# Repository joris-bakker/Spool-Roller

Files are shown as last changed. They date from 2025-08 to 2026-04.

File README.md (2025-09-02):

# Spool-Roller (Made by Josua T. and Joris Bakker)

WhatsApp Image

- ToDO: Nach Manual-Menu Stop, wenn man wieder zurückgeht, den Screen aktualisieren!
- Gehäuse für Platine
- 3D-Files hochladen 

All designs, CAD-Files and mechanical parts and were created by Josua T.

Software and PCB was made by Joris Bakker

# Device Function Description

The device is designed for winding various materials, such as wire, filament, or cable.  
The basic principle is based on two main components:

- **Guide Unit**: Moves smoothly back and forth to ensure the material is wound neatly and in parallel.  
- **Drive Roller**: Winds the material onto the spool.

This technology allows spools to be filled automatically and evenly.

---

## Operating Modes

### 1. Automatic Mode

The user specifies the following parameters:

- Number of windings  
- Wire diameter  
- Spool width  

The winding process is fully automated according to the set values.  
This mode is particularly suitable for manufacturing custom spools, such as induction coils.

---

### 2. Manual Mode

- No input of winding data required.  
- The winding speed is manually controlled via a rotary knob.

---

## Operating Instructions

### 1. Preparation

1. Power on the device.  
2. Select one of the two operating modes (Automatic or Manual) via the menu.  
3. If necessary, set the parameters (e.g., winding count, wire diameter, spool width).  

**Note:** During parameter entry, all motors are disabled and mechanically free to move.

---

### 2. Guide Zeroing

1. After entering the parameters, move the guide to the left edge of the guide rail.  
2. This position is set as the zero point.

---

### 3. Spool Preparation

1. Mount an empty spool on the device.  
   - The clamping mechanism works similarly to a lathe chuck.  
2. Thread the material (e.g., wire, filament, or cable) through the guide.  
3. Secure the material end firmly to the spool.  
4. Apply light tension to the material to ensure neat winding.

---

### 4. Starting the Winding Process

After zeroing, the selected operating mode starts automatically:

- **Automatic Mode:** Winding is performed according to the set parameters.  
- **Manual Mode:** Winding speed is controlled via the rotary knob.

---

## Software and Control Layout

### Control Concept

**Control Element:**  
All menu items are controlled via a rotary knob with a push function.

- **Rotate:** Navigate between menu items  
- **Push:** Select a menu item or confirm an entry  

**Display:**  
An OLED display shows all available functions, menus, and status messages of the device.

---

## Device Control

- **Main Switch:** Located on the device housing for turning the entire unit on/off.  
- **Power Supply:**  
  - Power adapter: 12 V, minimum 3 A output  
  - Power consumption: approx. 1.8 A during operation  

---

## Electronics Layout

- **Central Control Unit:**  
  - ESP32 microcontroller for motor control, display management, and user interaction  

- **Motor Drivers:**  
  - Two separate drivers for controlling the different motors  

- **Power Conversion:**  
  - DC-to-DC voltage converters for internal circuits and voltage adjustment  

---

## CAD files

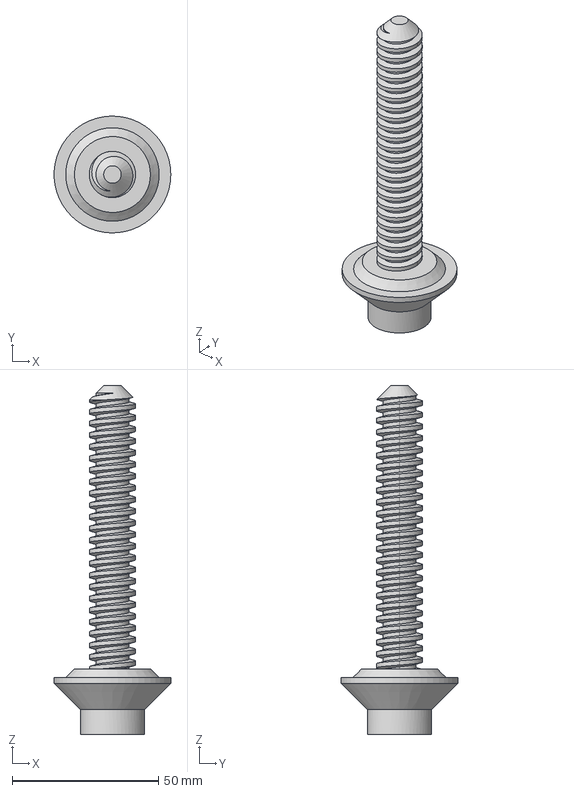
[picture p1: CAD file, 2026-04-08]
3D-Models/Spulenschraube.step
40.0 x 40.0 x 119.5 mm

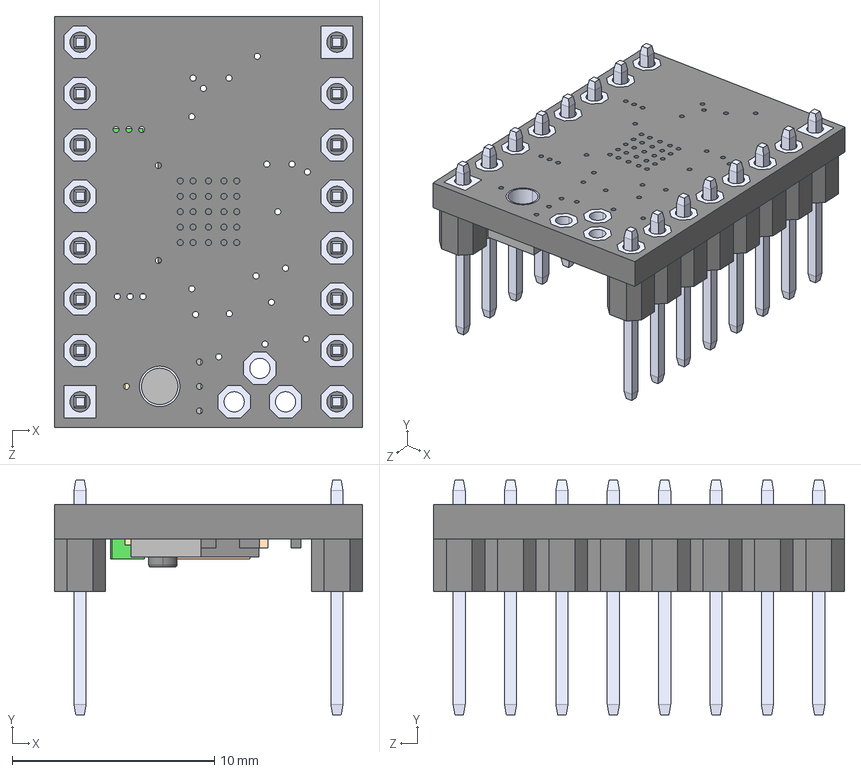
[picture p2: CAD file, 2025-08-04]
kiCad-FIles/additional_files/TMC2209_SILENTSTEPSTICK/TMC2209_SILENTSTEPSTICK.step
15.2 x 11.6 x 20.3 mm

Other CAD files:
kiCad-FIles/Spool_Roller/A4988_STEPPER_MOTOR_DRIVER_CARRIER/A4988_STEPPER_MOTOR_DRIVER_CARRIER.step

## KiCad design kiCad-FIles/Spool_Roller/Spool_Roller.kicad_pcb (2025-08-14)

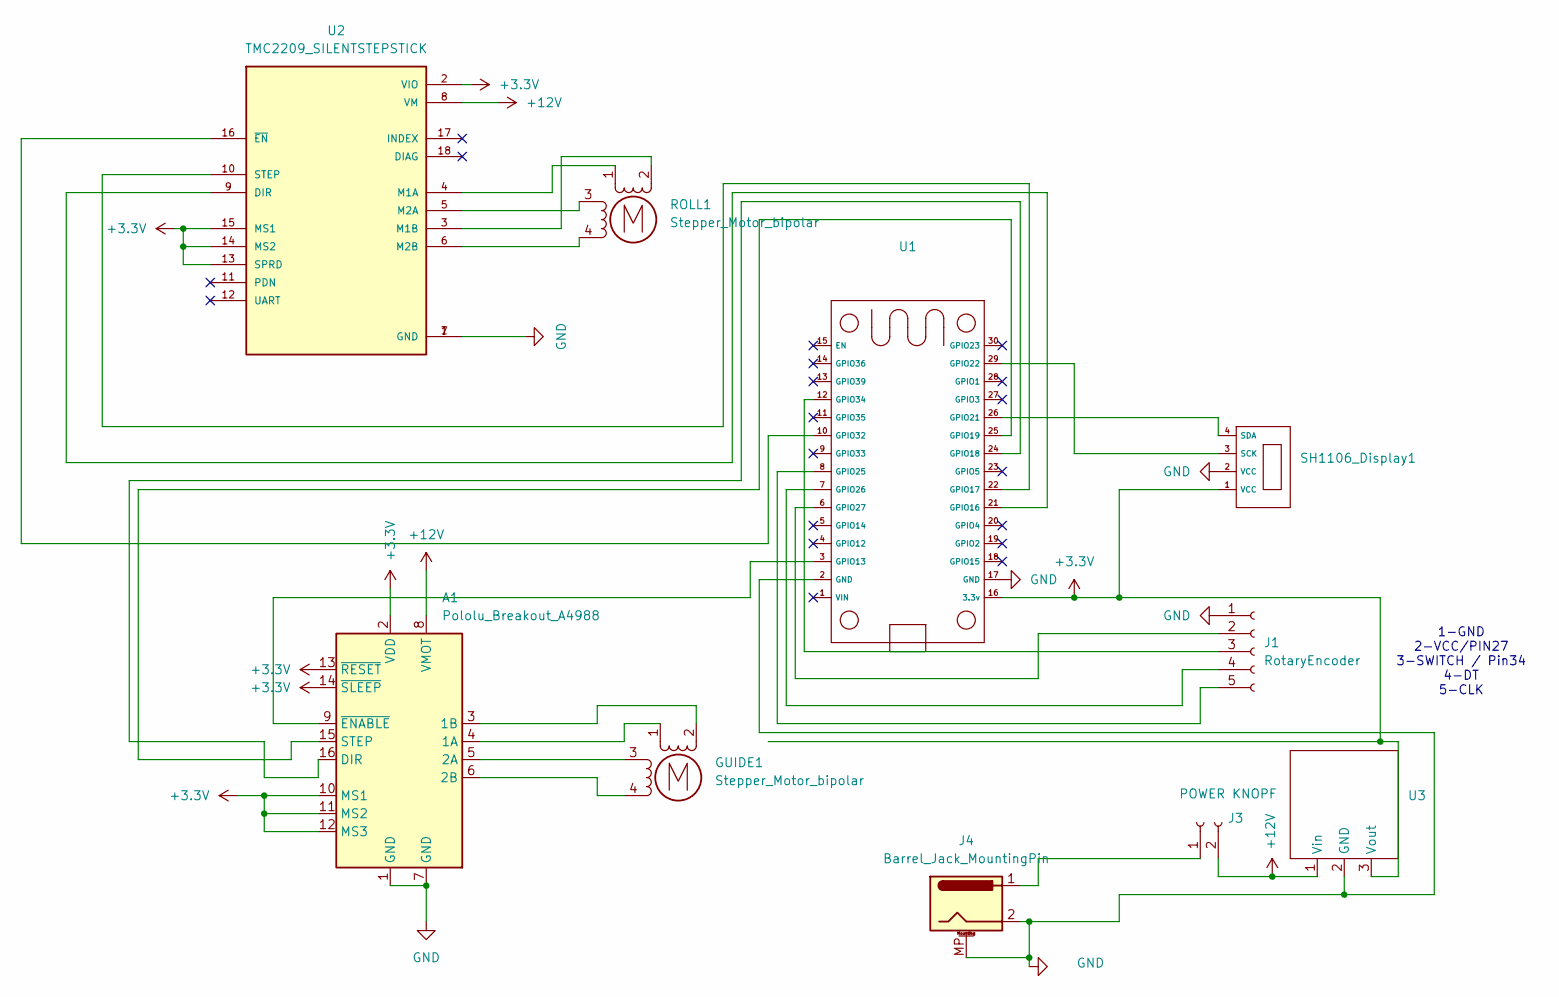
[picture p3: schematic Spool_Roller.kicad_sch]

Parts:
A1: Pololu_Breakout_A4988; Pololu_Breakout-16_15.2x20.3mm
GUIDE1: Stepper_Motor_bipolar; PinSocket_1x04_P2.00mm_Vertical
J1: RotaryEncoder; PinSocket_1x05_P2.54mm_Vertical
J3: POWER KNOPF; PinSocket_1x02_P2.54mm_Vertical
J4: Barrel_Jack_MountingPin; BarrelJack_Wuerth_6941xx301002
ROLL1: Stepper_Motor_bipolar; PinSocket_1x04_P2.00mm_Vertical
SH1106_Display1: PinSocket_1x04_P2.54mm_Vertical
U1: joris_esp32
U2: TMC2209_SILENTSTEPSTICK; MODULE_TMC2209_SILENTSTEPSTICK; PARTREV 1.20
U3: PinSocket_1x03_P2.54mm_Vertical

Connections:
+3.3V: A1.2 (VDD), A1.10 (MS1), A1.11 (MS2), A1.12 (MS3), A1.13 (~RESET), A1.14 (~SLEEP), SH1106_Display1.1 (VCC), U1.16 (3.3v), U2.2 (VIO), U2.13 (SPRD), U2.14 (MS2), U2.15 (MS1), U3.3 (Vout)
+12V: A1.8 (VMOT), J3.2, U2.8 (VM), U3.1 (Vin)
GND: A1.1 (GND), A1.7 (GND), J1.1, J4.2, J4.MP (MountPin), SH1106_Display1.2 (VCC), U1.2 (GND), U1.17 (GND), U2.1 (GND), U2.7 (GND), U3.2 (GND)
unnamed: A1.4 (1A), GUIDE1.1
unnamed: A1.3 (1B), GUIDE1.2 (-)
unnamed: A1.5 (2A), GUIDE1.3
unnamed: A1.6 (2B), GUIDE1.4
unnamed: A1.16 (DIR), U1.24 (GPIO18)
unnamed: A1.15 (STEP), U1.25 (GPIO19)
unnamed: A1.9 (~ENABLE), U1.3 (GPIO13)
unnamed: J1.2, U1.6 (GPIO27)
unnamed: J1.3, U1.12 (GPIO34)
unnamed: J1.4, U1.7 (GPIO26)
unnamed: J1.5, U1.8 (GPIO25)
unnamed: J3.1, J4.1
unnamed: ROLL1.2 (-), U2.3 (M1B)
unnamed: SH1106_Display1.3 (SCK), U1.29 (GPIO22)
unnamed: SH1106_Display1.4 (SDA), U1.26 (GPIO21)
unnamed: U1.21 (GPIO16), U2.9 (DIR)
unnamed: U1.22 (GPIO17), U2.10 (STEP)
unnamed: U1.10 (GPIO32), U2.16 (~EN)
unnamed: ROLL1.1, U2.4 (M1A)
unnamed: ROLL1.3, U2.5 (M2A)
unnamed: ROLL1.4, U2.6 (M2B)

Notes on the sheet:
1-GND 2-VCC/PIN27 3-SWITCH / Pin34 4-DT 5-CLK

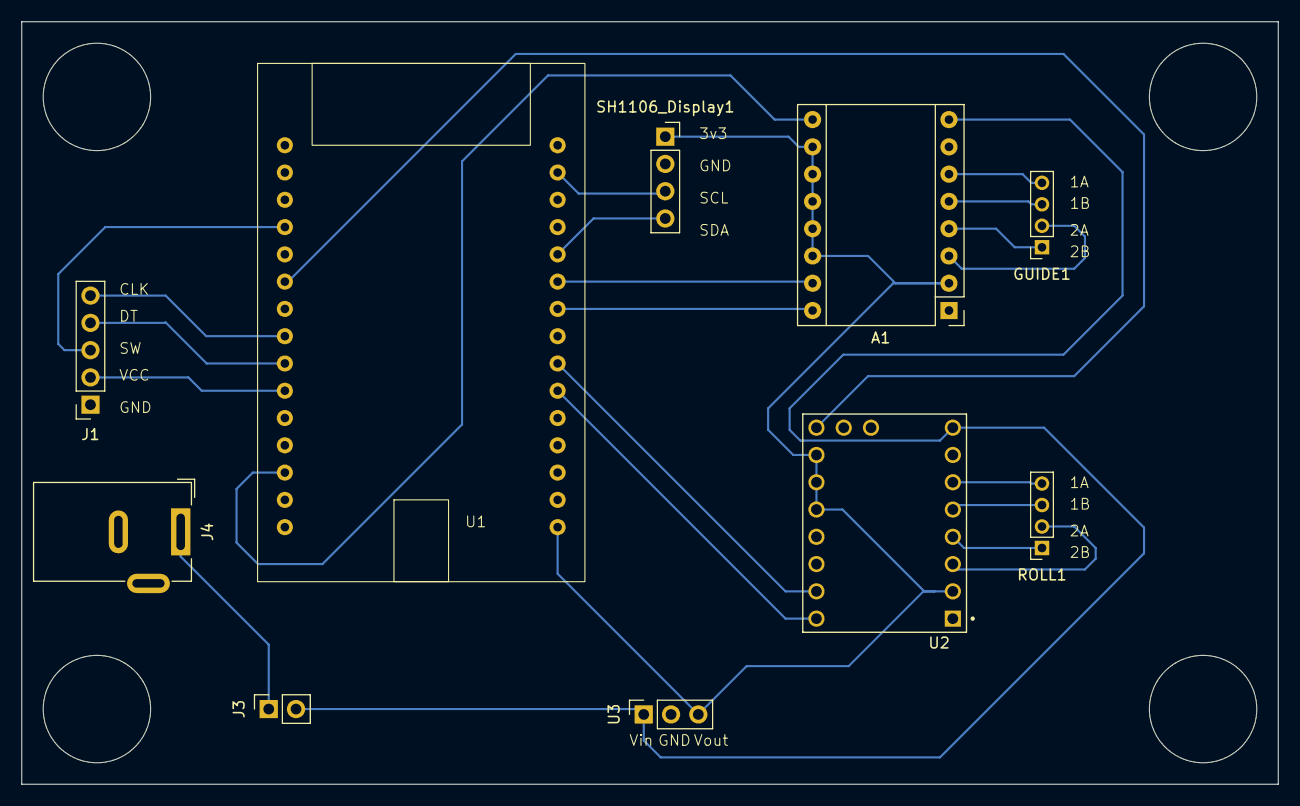
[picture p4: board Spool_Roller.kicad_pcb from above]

Board: 2 copper layers, 117.0 x 71.0 mm, 10 parts (0 on the bottom side), 24 nets.

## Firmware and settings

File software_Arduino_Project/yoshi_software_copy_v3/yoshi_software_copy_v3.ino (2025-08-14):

/*
Pins for Display: 3,3V,GND
SDA= D21
SCK= D22
*/


#include <SPI.h>
#include <Wire.h>
#include <Adafruit_GFX.h>
#include <Adafruit_SH110X.h>
#include <AccelStepper.h>
#include <Arduino.h>
#include <ESP32RotaryEncoder.h>










/// MOTOR SACHEN ///////////////////////////////////////////////////////////////
#define INTERFACETYPE 1 // Muss festgelegt werden
#define ROLL_STEP 17
#define ROLL_DIR 16
#define ENABLE_ROLL 32
#define ENABLE_GUIDE 13


bool directionToEnd = true;
long endposition = 20000;
// Zeitvariablen
unsigned long previousMillis = 0;
const unsigned long interval = 1000;  // 1000 Millisekunden
unsigned long currentMillis;

#define GUIDE_STEP 19
#define GUIDE_DIR 18

AccelStepper roll(INTERFACETYPE,ROLL_STEP, ROLL_DIR);
AccelStepper guide(INTERFACETYPE,GUIDE_STEP, GUIDE_DIR);
//////////////////////////////////////////////////////////////////////////////






// Change these to the actual pin numbers that you've connected your rotary encoder to
const int8_t  DO_ENCODER_VCC = 27; // VCC
const int8_t  DI_ENCODER_SW  = 33; // NOT RLY NEEDED
const uint8_t DI_ENCODER_A   = 25; // CLK
const uint8_t DI_ENCODER_B   = 26; // DT
int sw  = 0;
long currentPos = 0;
RotaryEncoder rotaryEncoder( DI_ENCODER_A, DI_ENCODER_B, DI_ENCODER_SW, DO_ENCODER_VCC );

/* Uncomment the initialize the I2C address , uncomment only one, If you get a totally blank screen try the other*/
#define i2c_Address 0x3c //initialize with the I2C addr 0x3C Typically eBay OLED's
                         // e.g. the one with GM12864-77 written on it
//#define i2c_Address 0x3d //initialize with the I2C addr 0x3D Typically Adafruit OLED's


#define SCREEN_WIDTH 128 // OLED display width, in pixels
#define SCREEN_HEIGHT 64 // OLED display height, in pixels
#define OLED_RESET -1   //   QT-PY / XIAO
Adafruit_SH1106G display = Adafruit_SH1106G(SCREEN_WIDTH, SCREEN_HEIGHT, &Wire, OLED_RESET);
const int pin34 = 34;

int manuell = 0;

int a=1;
int speed = 0;
int modus = 0;
int wickelmenge = 0;
float spulenbreite = 0;
float drahtbreite = 0;
int   y_linie = 19;
int y_linie_s = 39;
int   x_abstand = 10;
int w_ziffer_1= 0;
int w_ziffer_2 =0;
int w_ziffer_3 =0;
int w_ziffer_4 =0;
int s_ziffer_1= 0;
int s_ziffer_2 =0;
int s_ziffer_3 =0;

int d_ziffer_1= 0;
int d_ziffer_2 =0;
int d_ziffer_3 =0;






const uint8_t symbol_bitmap[] PROGMEM = {
  0x00, 0x00, 0x00, 0x00, 0x00, 0x00, 0x00, 0x00, 0x00, 0x00, 0x00, 0x00,
  0x00, 0x00, 0x00, 0x00, 0x30, 0x00, 0x00, 0x00, 0x00, 0x00, 0x00, 0x0C,
  0x30, 0x00, 0x00, 0x00, 0x00, 0x00, 0x00, 0x0C, 0x30, 0x00, 0x00, 0x00,
  0x00, 0x00, 0x00, 0x0C, 0x30, 0x03, 0x00, 0x00, 0x00, 0x00, 0x00, 0x0C,
  0x30, 0x1F, 0x00, 0x00, 0x00, 0x00, 0x00, 0x0C, 0x30, 0xFF, 0x00, 0x00,
  0x00, 0x00, 0x00, 0x0C, 0x37, 0xFF, 0xFF, 0xF0, 0x00, 0x00, 0x00, 0x0C,
  0x30, 0xFF, 0x00, 0x00, 0x00, 0x00, 0x00, 0x0C, 0x30, 0x1F, 0x00, 0x00,
  0x00, 0x00, 0x00, 0x0C, 0x30, 0x03, 0x00, 0x00, 0x00, 0x00, 0x00, 0x0C,
  0x30, 0x00, 0x00, 0x00, 0x00, 0x00, 0x00, 0x0C, 0x30, 0x00, 0x00, 0x00,
  0x00, 0x00, 0x00, 0x0C, 0x38, 0x00, 0x00, 0x00, 0x00, 0x00, 0x00, 0x1C,
  0x3F, 0xFF, 0xFF, 0xFF, 0xFF, 0xFF, 0xFF, 0xFC, 0x3F, 0xFF, 0xFF, 0xFF,
  0xFF, 0xFF, 0xFF, 0xFC, 0x38, 0x00, 0x00, 0x00, 0x00, 0x00, 0x00, 0x1C,
  0x30, 0x00, 0x00, 0x00, 0x00, 0x00, 0x00, 0x0C, 0x30, 0x00, 0x00, 0x00,
  0x00, 0x00, 0x00, 0x0C, 0x30, 0x00, 0x00, 0x00, 0x00, 0x00, 0x00, 0x0C,
  0x30, 0x00, 0x00, 0x00, 0x00, 0x00, 0x00, 0x0C, 0x30, 0x00, 0x00, 0x00,
  0x00, 0x00, 0x00, 0x0C, 0x30, 0x00, 0x00, 0x00, 0x00, 0x00, 0x00, 0x0C,
  0x30, 0x00, 0x00, 0x00, 0x00, 0x00, 0x00, 0x0C, 0x30, 0x00, 0x00, 0x00,
  0x00, 0x00, 0x00, 0x0C, 0x30, 0x00, 0x00, 0x00, 0x00, 0x00, 0x00, 0x0C,
  0x30, 0x00, 0x00, 0x00, 0x00, 0x00, 0x00, 0x0C, 0x30, 0x00, 0x00, 0x00,
  0x00, 0x00, 0x00, 0x0C, 0x30, 0x00, 0x00, 0x00, 0x00, 0x00, 0x00, 0x0C,
  0x00, 0x00, 0x00, 0x00, 0x00, 0x00, 0x00, 0x00, 0x00, 0x00, 0x00, 0x00,
  0x00, 0x00, 0x00, 0x00
};


void knobCallback( long value )
{
    // This gets executed every time the knob is turned
    currentPos = value;
    
}

void buttonCallback( unsigned long duration )
{
    // This gets executed every time the pushbutton is pressed
    sw = 1;
    
}


int lastStableState = HIGH;            // letzter stabiler Zustand
int lastReading = HIGH;                // letzter gelesener Zustand
unsigned long lastDebounceTime = 0;    // Zeitstempel für Entprellung
const unsigned long debounceDelay = 20; // Entprellzeit in ms

// Für rotary

long lastPos    = 0;

String currentDir = "";
String lastDir    = "";
int reading;


bool firstCall = true;
bool firstCall_manual = true;
bool firstCall_auto = true;





void setup() {
  // put your setup code here, to run once:
   Serial.begin(9600);






  delay(250); // wait for the OLED to power up
  display.begin(i2c_Address, true); // Address 0x3C default
 //display.setContrast (0); // dim display
  delay(2000);
  display.clearDisplay();
  display.setTextSize(1);
  display.setTextColor(SH110X_WHITE);
  display.setCursor(50, 50);

/////////////////////////////////////////// ROTARY ENCODER ///////////////////////////////

  pinMode(pin34, INPUT);
  
 // This tells the library that the encoder has its own pull-up resistors
    rotaryEncoder.setEncoderType( EncoderType::HAS_PULLUP );

    // Range of values to be returned by the encoder: minimum is 1, maximum is 10
    // The third argument specifies whether turning past the minimum/maximum will
    // wrap around to the other side:
    //  - true  = turn past 10, wrap to 1; turn past 1, wrap to 10
    //  - false = turn past 10, stay on 10; turn past 1, stay on 1
    rotaryEncoder.setBoundaries( 0, 9, true );

    // The function specified here will be called every time the knob is turned
    // and the current value will be passed to it
    rotaryEncoder.onTurned( &knobCallback );



    // This is where the inputs are configured and the interrupts get attached
    rotaryEncoder.begin();

///////////////////////////////////////////////////////////////////////////////////////////////

/////////////// MOTOR ///////////////////////////////////////////////
roll.setMaxSpeed(5000);
guide.setMaxSpeed(5000);

guide.setAcceleration(50000);
roll.setAcceleration(50000);
/////////////////////////////////////////////////////////////////////
 
 pinMode(ENABLE_ROLL, OUTPUT); // FÜR GUIDE --> LOW = AN
 pinMode(ENABLE_GUIDE, OUTPUT); // FÜR ROLL

 digitalWrite(ENABLE_ROLL,HIGH);
 digitalWrite(ENABLE_GUIDE,HIGH);
}


void loop() {

currentMillis = millis();
reading = digitalRead(pin34);

  // Hat sich der Zustand geändert?
  if (reading != lastReading) {
    lastDebounceTime = millis();  // Zeit merken
  }


  // Wenn genug Zeit vergangen ist, Zustand übernehmen
  if ((millis() - lastDebounceTime) > debounceDelay) {
    if (reading != lastStableState) {
      lastStableState = reading;


      // Nur wenn Taste gedrückt (LOW)
      if (lastStableState == LOW) {
       
        sw = 1;
        // Hier deine Aktion
      }else{
        sw=0;
      };
    }
  }


  lastReading = reading;




 
switch(a) {
  case 1: //MENü
          main_menu();

           break;

  case 2: //AUTO
       auto_menu();
        break;


  case 3:  //Wickeln
        menu_wickeln();
         break;


  case 4:  //Spuelen
        menu_spulenbreite();
        break;


  case 5: //Set Speed 1
         manu_menu();
        break;
         


  case 6: // Start/Back
          manu_stop();
          break;

  case 7: //bisher unnötig
          display.clearDisplay();
          display.setCursor(5,20);
          display.print("Set Speed1:");

          
          display.setCursor(5,40);
          display.print("Set Speed2: lalala");
          display.display();

          if(sw == 1)
          {
            a = 6;
            
          };
          break;
  case 8: // AUTOMODUS LÄUFT!!!

          auto_motor(3000, spulenbreite, drahtbreite, wickelmenge);
          
          if(roll.distanceToGo()==0)
          {
              display.clearDisplay();
              display.setCursor(10,22);
              display.print("Menu ist Fertig!");
              display.setCursor(10,43);
              display.print("Press to go Menu!");
              display.display();
          };
          
          /// Hier Läuft der Motor!!
          // So klein  wie möglich gehalten werden für berechnungszeiten von Motor


          if(sw == 1)
          {
            a = 1;
            roll.stop();
            guide.stop();
          rotaryEncoder.setBoundaries(0,10, false );
          rotaryEncoder.setEncoderValue(0);
          currentPos=0;

          };
          break;

  case 9: //1000er
      ziffer_1();
      break;
  
  case 10: //100er
        ziffer_2();
        break;

  case 11: //10er
      ziffer_3();
      break;

  case 12: //1er
      ziffer_4();
      break;

    case 13: //1000er
      ziffer_1_s();
      break;
  
  case 14: //100er
        ziffer_2_s();
        break;

  case 15: //10er
      ziffer_3_s();
      break;

  case 16: //Motor Controller, Spulenweite already set
      Serial.print("case16, Motor Controlling");
      break;

  
  case 17: // Drahtbreite
      menu_drahtbreite();
      // Hier muss code für drahtbreite stehen
      break;

  case 18: // HIER STEHT CODE FÜR AUTO ZEROING

      menu_zeroing();


      break;

  case 19: //1000er
      ziffer_1_d();
      break;
  
  case 20: //100er
        ziffer_2_d();
        break;

  case 21: //10er
      ziffer_3_d();
      break;
  


  default: printf("KP"); break;
}


sw = 0;


}






 

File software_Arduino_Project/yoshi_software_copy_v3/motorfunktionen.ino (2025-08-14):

int calc_endposition(float spulenbreite)
{

 int steigung = 2 ; // in mm
 int stepsPerRevolution = 200;
 int microsteps = 4; // muss angepasst werden 

 int steps = (spulenbreite*stepsPerRevolution*microsteps)/steigung;
 
 return steps;
};


float calc_speed_guide(long manual_speed, float drahtbreite)
{
	int steigung = 2;
	int stepsPerRevolution = 200;
	int microsteps_guide = 4;
	int microsteps_roll  = 16;

	int steps_guide = (drahtbreite*stepsPerRevolution*microsteps_guide)/steigung;
	int steps_roll = stepsPerRevolution*microsteps_roll;

	float speed = manual_speed *(float(steps_guide)/float(steps_roll));
	
	return speed;
};


void manual_motor(int speed, float spulenbreite, float drahtbreite)
{

		
		if (firstCall_manual)
			{
				rotaryEncoder.setBoundaries( 0, 100, false );
				rotaryEncoder.resetEncoderValue();
				endposition = calc_endposition(spulenbreite-drahtbreite);
				Serial.println(endposition);
 			currentPos = 0;
			
			firstCall_manual = false;
			};
     // Roll-Motor → kontinuierlich
  roll.setSpeed(speed);
  roll.runSpeed();


  // Guide-Motor → pendeln
  guide.setMaxSpeed(calc_speed_guide(speed, drahtbreite));  // aktuelle Geschwindigkeit setzen
  guide.run();               // moveTo() aktiv ausführen

  // Wenn Ziel erreicht: Richtung umkehren
  if (guide.distanceToGo() == 0) {
    if (directionToEnd) {
      guide.moveTo(0);
    } else {
      guide.moveTo(endposition);
    }
    directionToEnd = !directionToEnd;
  }
};


// Konfiguration
// Bewegungsgrenze

void auto_motor(int speed, float spulenbreite, float drahtbreite, int turns)
{
	
		if (firstCall_auto)
			{
			guide.setAcceleration(50000);	
			
			guide.setMaxSpeed(calc_speed_guide(speed, drahtbreite));
			endposition = calc_endposition(spulenbreite-drahtbreite);
			Serial.println(endposition);
			roll.setMaxSpeed(speed);
			roll.moveTo(turns*200*16);
 			currentPos = 0;
			firstCall_auto = false;
			};
     // Roll-Motor → kontinuierlich
  
	roll.run();
	if(roll.distanceToGo()>0)
		{
    // aktuelle Geschwindigkeit setzen
  	guide.run();               // moveTo() aktiv ausführen

  	// Wenn Ziel erreicht: Richtung umkehren
  	if (guide.distanceToGo() == 0) {
    	if (directionToEnd) {
      	guide.moveTo(0);
    	} else {
      	guide.moveTo(endposition);
    	}
    	directionToEnd = !directionToEnd;
  		}
	};
};

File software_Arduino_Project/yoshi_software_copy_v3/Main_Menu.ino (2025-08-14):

          

void main_menu(void){
  
  digitalWrite(ENABLE_GUIDE,HIGH);
  digitalWrite(ENABLE_ROLL,HIGH);


  display.clearDisplay();
  display.setCursor(30,2);
  display.drawLine(30,11,90,11,SH110X_WHITE);
  display.print("Main Menu:");
  display.setCursor(10,30);
  display.print("Auto");
  firstCall = true;
  firstCall_manual = true;
  firstCall_auto = true;
  


          
  display.setCursor(60, 30);
  display.print("Manual");

  if(currentPos % 2 == 0){
    modus = 1;
    display.drawRect(5,25,35,17,SH110X_WHITE);
      }
  if(currentPos %2 == 1) {
    modus = 2;
    display.drawRect(55,25,45,17,SH110X_WHITE);
    };
  display.display();

  if(sw == 1)
    {
    if(modus ==1){
      a = 2;
      rotaryEncoder.setEncoderValue(0);
      currentPos= 0;
      };
    if(modus == 2){
      a = 4;
      manuell = 1;
      };
    modus= 0;
    
          
     };

      }

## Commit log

2025-08-04 kicad_files_unfinised
    its not ready yet
    [A4988_STEPPER_MOTOR_DRIVER_CARRIER.step, Spool_Roller.kicad_pcb, Spool_Roller.kicad_sch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]
2025-08-14 gerberfiles, pcb, software
    those should be the final code, pcb etc.
    [Spool_Roller-B_Cu.gbr, Spool_Roller-B_Mask.gbr, Spool_Roller-B_Paste.gbr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]
